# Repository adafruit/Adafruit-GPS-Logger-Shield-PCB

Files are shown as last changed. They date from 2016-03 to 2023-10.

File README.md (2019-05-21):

## Adafruit GPS Logger Shield PCB
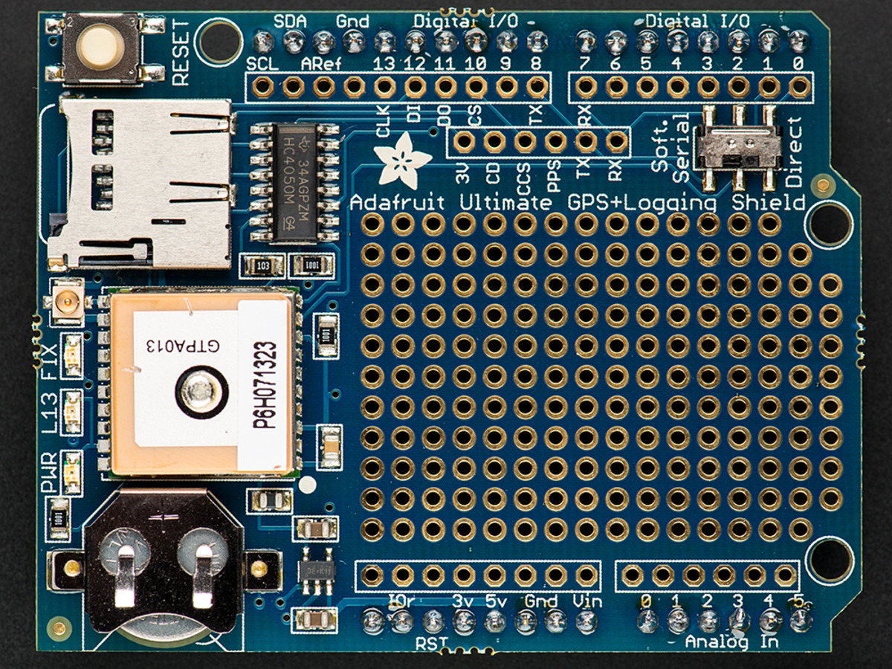
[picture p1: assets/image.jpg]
<a href="http://www.adafruit.com/products/1272"><br/>
Click here to purchase one from the Adafruit shop</a>

Better than ever, our Adafruit assembled GPS shield comes with an Ultimate GPS module. This GPS shield works great with either Adafruit Metro, Arduino UNO or Leonardo and is designed to log data to an SD card. Or you can leave the SD card out and use the GPS for a geocaching project, or maybe a music player that changes tunes depending on where you are in the city.
 
- -165 dBm sensitivity, 10 Hz updates, 66 channels
- Low power module - only 20mA current draw, half of most GPS's
- Assembled & tested shield for Arduino Uno/Duemilanove/Diecimila/Leonardo (not for use with Mega/ADK/Due)
- MicroSD card slot for datalogging onto a removable card
- RTC battery included, for up to 7 years backup
- Built-in datalogging to flash
- PPS output on fix
- Internal patch antenna + u.FL connector for external active antenna
- Power, Pin #13 and Fix status LED
- Big prototyping area

PCB files for Adafruit GPS Logger Shield. The format is EagleCAD schematic and board layout
- https://www.adafruit.com/products/1272

### License

Adafruit invests time and resources providing this open source design, please support Adafruit and open-source hardware by purchasing products from [Adafruit](https://www.adafruit.com)!

All text above must be included in any redistribution

Designed by Limor Fried/Ladyada for Adafruit Industries.
Creative Commons Attribution/Share-Alike, all text above must be included in any redistribution. 
See license.txt for additional information.

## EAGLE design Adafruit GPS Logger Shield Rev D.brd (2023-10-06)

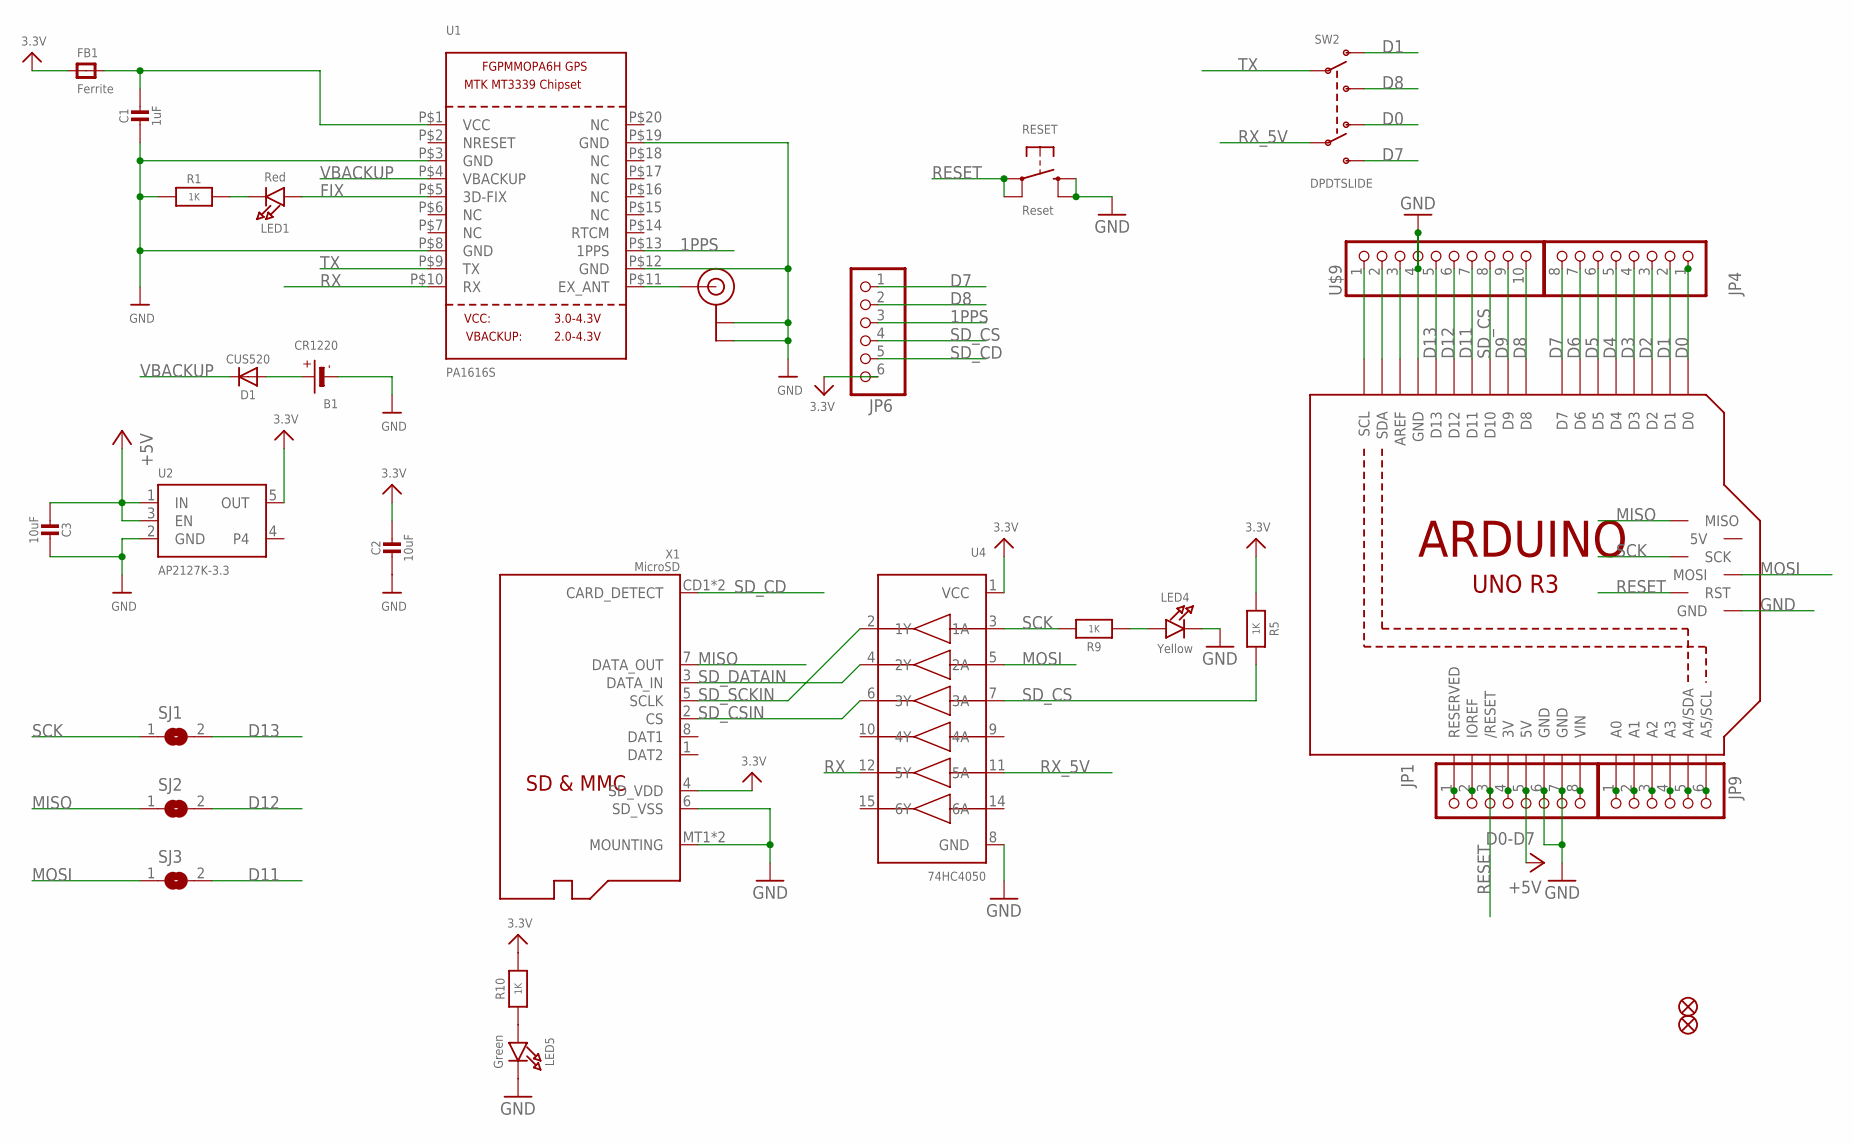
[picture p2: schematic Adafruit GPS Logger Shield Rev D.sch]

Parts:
B1: CR1220
C1: 1uF; 0805-NO
C2, C3: 10uF; 0805-NO
D1: CUS520; SOD-323
FB1: Ferrite; 0805
FID1, FID2: FIDUCIAL_1MM
JP1: D0-D7; 1X08-BIG
JP4: PINHD-1X8BIG; 1X08-BIG
JP6, JP9: PINHD-1X6B; 1X06-BIG
LED1: Red; CHIPLED_0805_NOOUTLINE
LED4: Yellow; CHIPLED_0805_NOOUTLINE
LED5: Green; CHIPLED_0805_NOOUTLINE
M1: ARDUINO_R3_ICSP; ARDUINOR3_ICSP
R1, R5, R9, R10: 1K; 0805-NO
RESET: Reset; 6MMX6MM_TACTILE_SMT
SJ1, SJ2, SJ3: SOLDERJUMPER; SOLDERJUMPER_ARROW_NOPASTE
SW2: DPDTSLIDE; EG1390
U1: PA1616S; FGPMMOPA6H
U2: AP2127K-3.3; SOT23-5
U4: 74HC4050; SOIC16
U$9: PINHD-1X10; 1X10-BIG
X1: MicroSD; MICROSD
X2: u.FL; U.FL

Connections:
1PPS: JP6.3, U1.P$13 (1PPS)
3.3V: C2.1, FB1.1, JP6.6, R5.1, R10.2, U2.5 (OUT), U4.1 (VCC), X1.4 (SD_VDD)
3V: JP1.4, M1.3V
+5V: C3.1, JP1.5, M1.5V, U2.1 (IN), U2.3 (EN)
A0: JP9.1, M1.A0
A1: JP9.2, M1.A1
A2: JP9.3, M1.A2
A3: JP9.4, M1.A3
A4: JP9.5, M1.A4 (A4/SDA)
A5: JP9.6, M1.A5 (A5/SCL)
AREF: M1.AREF, U$9.3
D0: JP4.1, M1.D0, SW2.O2
D1: JP4.2, M1.D1, SW2.O1
D2: JP4.3, M1.D2
D3: JP4.4, M1.D3
D4: JP4.5, M1.D4
D5: JP4.6, M1.D5
D6: JP4.7, M1.D6
D7: JP4.8, JP6.1, M1.D7, SW2.S2
D8: JP6.2, M1.D8, SW2.S1, U$9.10
D9: M1.D9, U$9.9
D11: M1.D11, SJ3.2, U$9.7
D12: M1.D12, SJ2.2, U$9.6
D13: M1.D13, SJ1.2, U$9.5
FIX: LED1.A, U1.P$5 (3D-FIX)
GND: B1.-, C1.2, C2.2, C3.2, JP1.6, JP1.7, LED4.C, LED5.C, M1.GND, M1.GND@1 (GND), M1.GND@2 (GND), M1.GND@3 (GND), R1.1, RESET.B (S), RESET.B' (S1), U1.P$3 (GND), U1.P$8 (GND), U1.P$12 (GND), U1.P$19 (GND), U2.2 (GND), U4.8 (GND), U$9.4, X1.6 (SD_VSS), X1.MT1 (MOUNTING), X1.MT2 (MOUNTING), X2.1 (GND), X2.2 (GND)
IOREF: JP1.2, M1.IOREF
MISO: M1.MISO, SJ2.1, X1.7 (DATA_OUT)
MOSI: M1.MOSI, SJ3.1, U4.5 (2A)
unnamed: C1.1, FB1.2, U1.P$1 (VCC)
unnamed: LED1.C, R1.2
unnamed: B1.+$1 (+), B1.+$2 (+), D1.A
unnamed: U1.P$11 (EX_ANT), X2.3 (SIGNAL)
unnamed: LED4.A, R9.1
unnamed: LED5.A, R10.1
NC: JP1.1, M1.RESERVED
RESET: JP1.3, M1.RESET (/RESET), M1.RESET_ICSP (RST), RESET.A, RESET.A' (P1)
RX: U1.P$10 (RX), U4.12 (5Y)
RX_5V: SW2.P2, U4.11 (5A)
SCK: M1.SCK, R9.2, SJ1.1, U4.3 (1A)
SCL: M1.SCL, U$9.1
SDA: M1.SDA, U$9.2
SD_CD: JP6.5, X1.CD1 (CARD_DETECT), X1.CD2 (CARD_DETECT)
SD_CS: JP6.4, M1.D10, R5.2, U4.7 (3A), U$9.8
SD_CSIN: U4.6 (3Y), X1.2 (CS)
SD_DATAIN: U4.4 (2Y), X1.3 (DATA_IN)
SD_SCKIN: U4.2 (1Y), X1.5 (SCLK)
TX: SW2.P1, U1.P$9 (TX)
VBACKUP: D1.C, U1.P$4 (VBACKUP)
VIN: JP1.8, M1.VIN

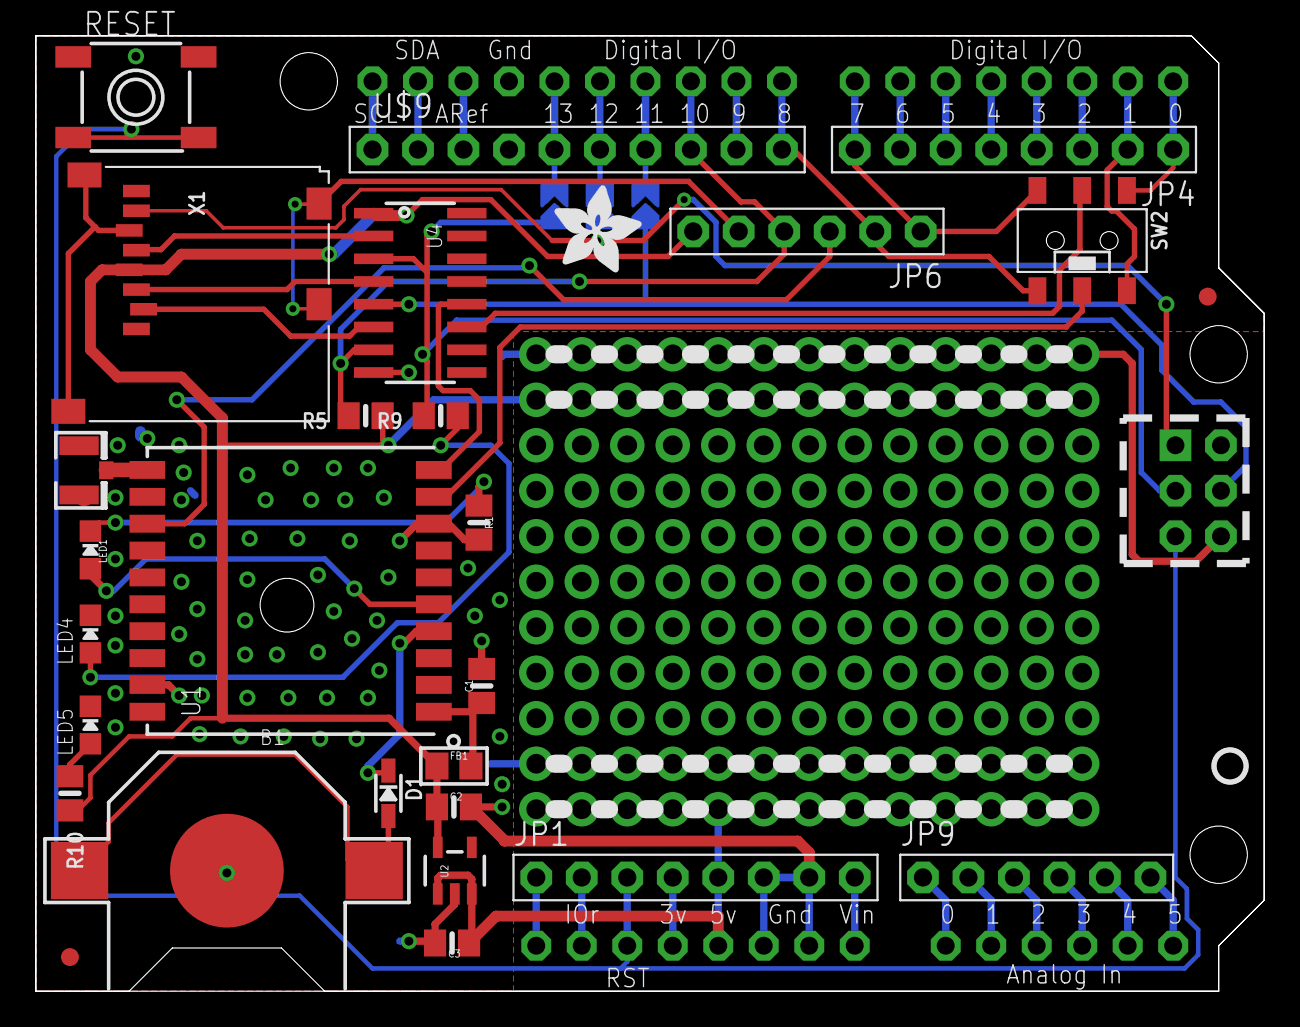
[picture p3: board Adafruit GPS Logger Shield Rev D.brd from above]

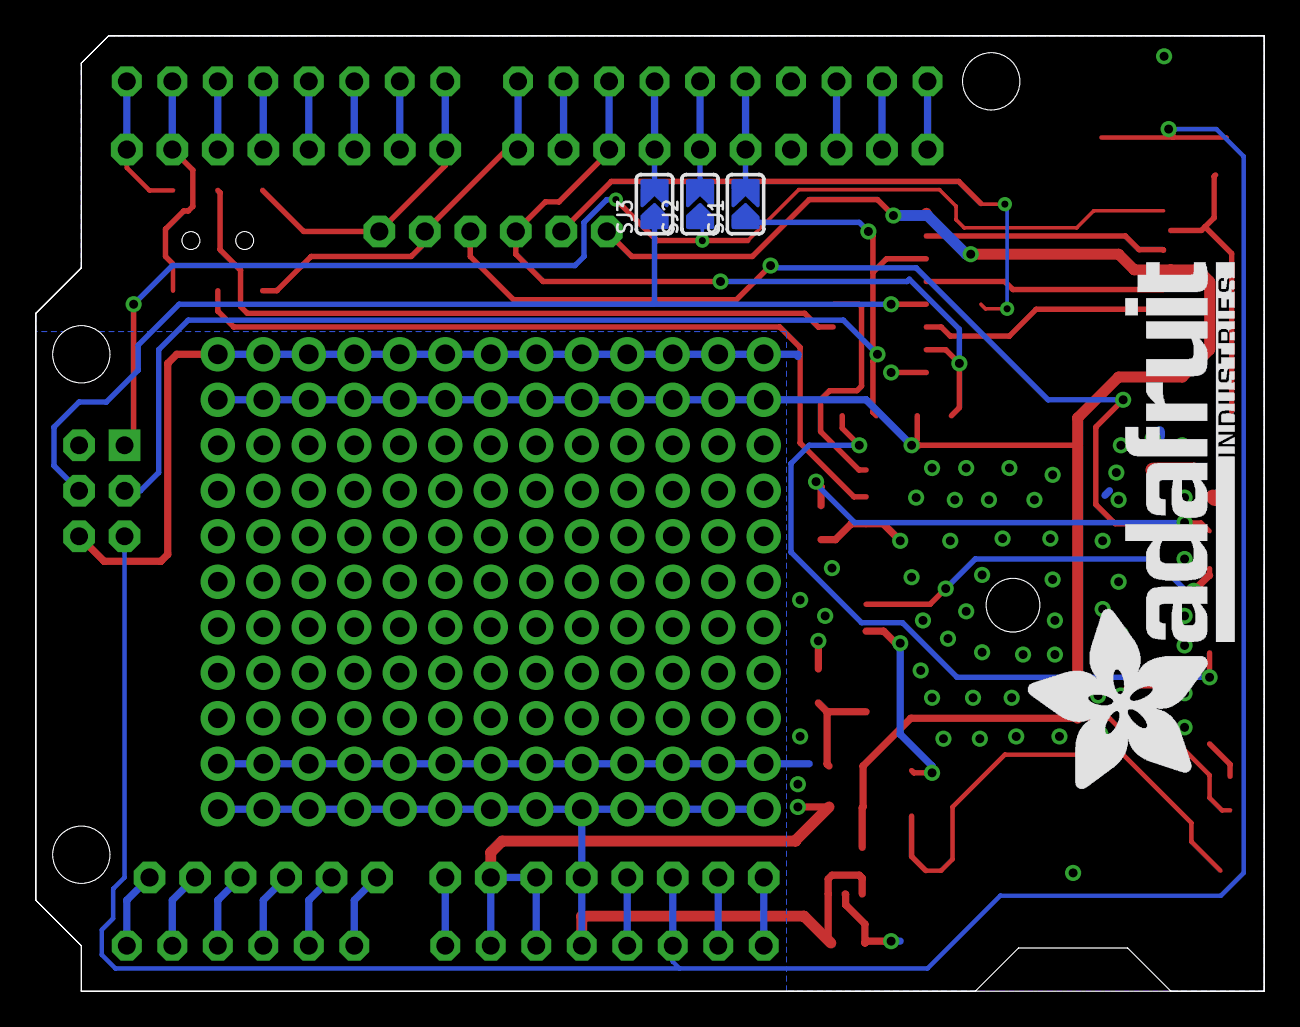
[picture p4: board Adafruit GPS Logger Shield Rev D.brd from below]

Board: 2 copper layers, 68.6 x 53.3 mm, 59 parts (7 on the bottom side), 50 nets.

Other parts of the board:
PLABEL0: PLABEL0
PLABEL1: PLABEL1
PLABEL2: PLABEL2
PLABEL3: PLABEL3
PLABEL4: PLABEL4
PLABEL5: PLABEL5
PLABEL6: PLABEL6
PLABEL7: PLABEL7
PLABEL8: PLABEL8
PLABEL9: PLABEL9
PLABEL10: PLABEL10
PLABEL11: PLABEL11
PLABEL12: PLABEL12
PLABEL13: PLABEL13
PLABEL14: PLABEL14
PLABEL15: PLABEL15
PLABEL16: PLABEL16
PLABEL17: PLABEL17
PLABEL18: PLABEL18
PLABEL19: PLABEL19
PLABEL20: PLABEL20
PLABEL21: PLABEL21
PLABEL22: PLABEL22
PLABEL23: PLABEL23
PLABEL24: PLABEL24
U$13: ADAFRUIT_5MM
U$15: ADAFRUIT_TEXT_30MM
U$16: PCBFEAT-REV-040

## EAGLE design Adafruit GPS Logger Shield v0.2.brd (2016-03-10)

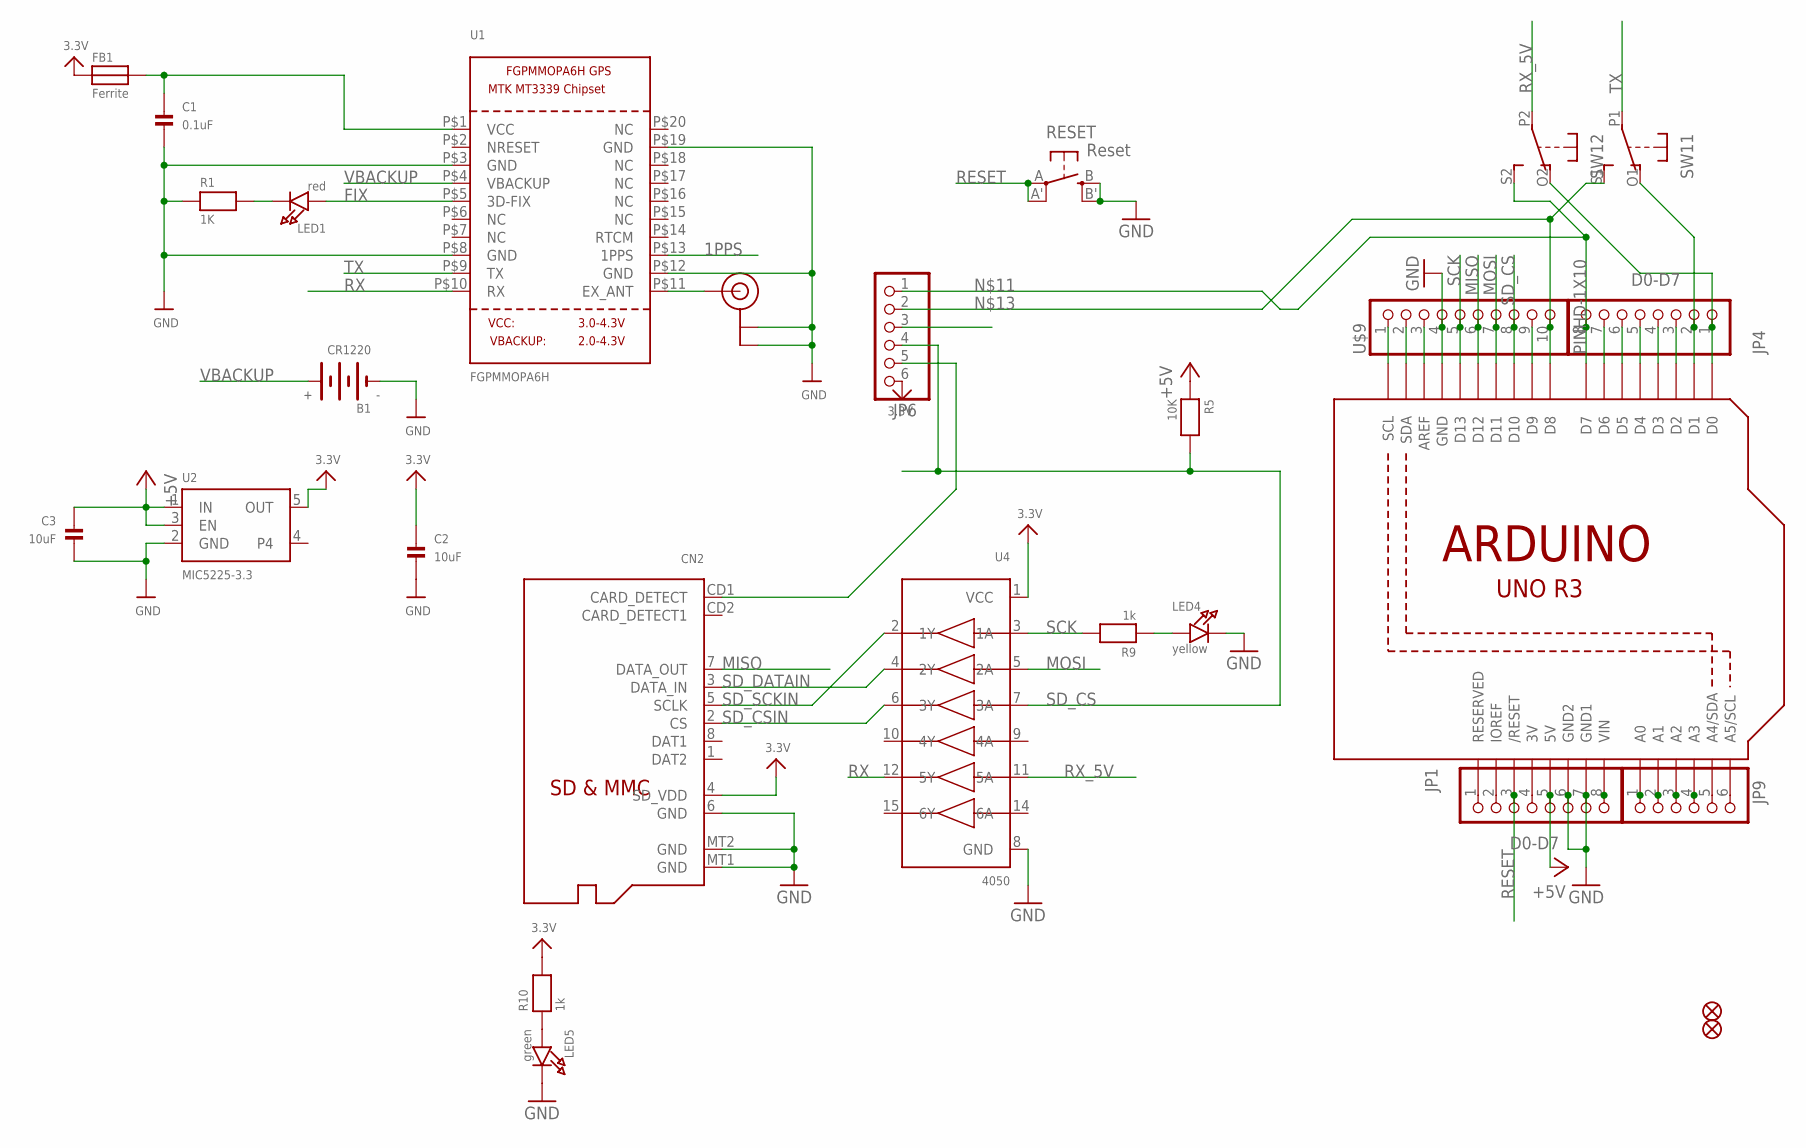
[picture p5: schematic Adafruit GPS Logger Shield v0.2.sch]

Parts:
B1: CR1220
C1: 0.1uF; 0805@1
C2, C3: 10uF; 0805@1
CN2: MICROSD
FB1: Ferrite; 0805@1
FID1, FID2: FIDUCIAL""; FIDUCIAL_1MM
JP1, JP4: D0-D7; 1X08-BIG
JP6, JP9: PINHD-1X6B; 1X06-BIG
LED1: red; CHIPLED_0805
LED4: yellow; CHIPLED_0805
LED5: green; CHIPLED_0805
R1: 1K; 0805
R5: 10K; 0805
R9, R10: 1k; 0805
RESET: Reset; EVQ-Q2
SW1: DPDT-EG1390; EG1390
U1: FGPMMOPA6H
U2: MIC5225-3.3; SOT23-5
U3: ARDUINOR3-DIMENSION; ARDUINOR3
U4: 4050; SOIC16
U$9: PINHD-1X10; 1X10-BIG
U$20: U.FL

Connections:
1PPS: JP6.3, U1.P$13 (1PPS)
3.3V: C2.1, CN2.4 (SD_VDD), FB1.1, JP6.6, R10.2, U2.5 (OUT), U4.1 (VCC)
+5V: C3.1, JP1.5, R5.1, U2.1 (IN), U2.3 (EN), U3.5V
FIX: LED1.A, U1.P$5 (3D-FIX)
GND: B1.-, C1.2, C2.2, C3.2, CN2.6 (GND), CN2.MT1 (GND), CN2.MT2 (GND), JP1.6, JP1.7, LED4.C, LED5.C, R1.1, RESET.B (S), RESET.B' (S1), U1.P$3 (GND), U1.P$8 (GND), U1.P$12 (GND), U1.P$19 (GND), U2.2 (GND), U3.GND, U3.GND1, U3.GND2, U4.8 (GND), U$9.4, U$20.P$1 (GND), U$20.P$2 (GND)
MISO: CN2.7 (DATA_OUT), U3.D12, U$9.6
MOSI: U3.D11, U4.5 (2A), U$9.7
unnamed: C1.1, FB1.2, U1.P$1 (VCC)
unnamed: LED1.C, R1.2
unnamed: JP1.1, U3.RESERVED
unnamed: U1.P$11 (EX_ANT), U$20.P$3 (SIGNAL)
unnamed: JP1.2, U3.IOREF
unnamed: JP1.4, U3.3V
unnamed: U3.SCL, U$9.1
unnamed: LED4.A, R9.1
unnamed: JP9.6, U3.A5 (A5/SCL)
unnamed: JP9.5, U3.A4 (A4/SDA)
unnamed: JP4.8, JP6.1, SW1.S2 (S), U3.D7
unnamed: U3.SDA, U$9.2
unnamed: JP6.2, SW1.S1 (S), U3.D8, U$9.10
unnamed: JP4.2, SW1.O1 (O), U3.D1
unnamed: JP1.8, U3.VIN
unnamed: JP4.3, U3.D2
unnamed: JP4.4, U3.D3
unnamed: JP4.5, U3.D4
unnamed: JP4.6, U3.D5
unnamed: JP4.7, U3.D6
unnamed: U3.AREF, U$9.3
unnamed: U3.D9, U$9.9
unnamed: LED5.A, R10.1
unnamed: JP9.1, U3.A0
unnamed: JP9.2, U3.A1
unnamed: JP9.3, U3.A2
unnamed: JP9.4, U3.A3
unnamed: JP4.1, SW1.O2 (O), U3.D0
RESET: JP1.3, RESET.A, RESET.A' (P1), U3.RESET (/RESET)
RX: U1.P$10 (RX), U4.12 (5Y)
RX_5V: SW1.P2, U4.11 (5A)
SCK: R9.2, U3.D13, U4.3 (1A), U$9.5
SD_CD: CN2.CD1 (CARD_DETECT), JP6.5
SD_CS: JP6.4, R5.2, U3.D10, U4.7 (3A), U$9.8
SD_CSIN: CN2.2 (CS), U4.6 (3Y)
SD_DATAIN: CN2.3 (DATA_IN), U4.4 (2Y)
SD_SCKIN: CN2.5 (SCLK), U4.2 (1Y)
TX: SW1.P1, U1.P$9 (TX)
VBACKUP: B1.+$1 (+), U1.P$4 (VBACKUP)

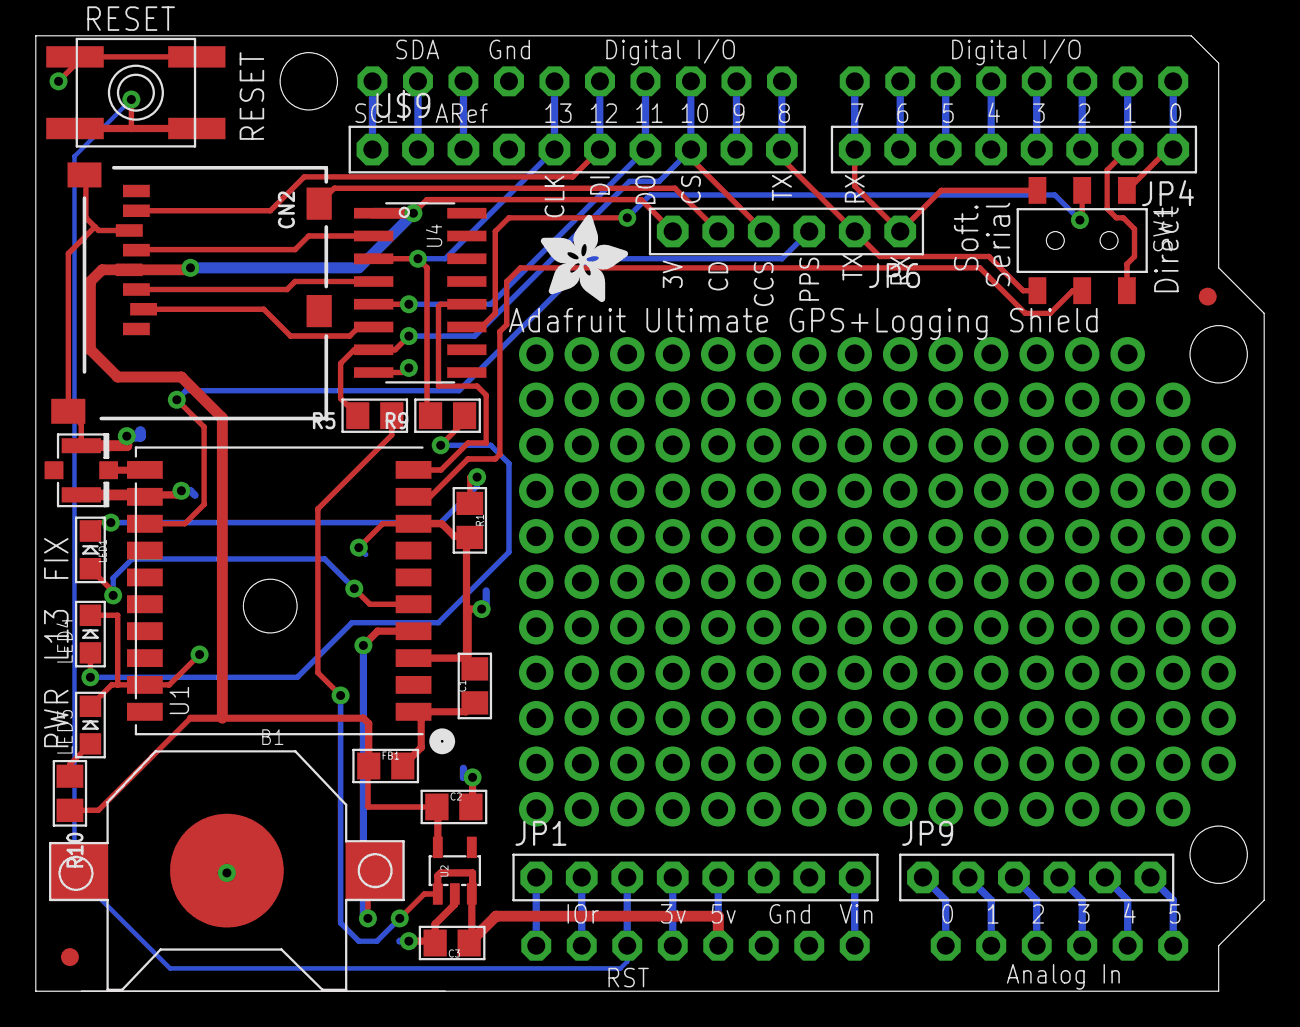
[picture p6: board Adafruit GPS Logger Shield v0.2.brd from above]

Board: 2 copper layers, 68.6 x 53.3 mm, 29 parts (1 on the bottom side), 46 nets.

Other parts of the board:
U$13: ADAFRUIT_5MM
U$15: ADAFRUIT_TEXT_30MM
